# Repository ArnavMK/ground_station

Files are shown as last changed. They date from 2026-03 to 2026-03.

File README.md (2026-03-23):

# Glacadóir: Handheld Rocketry Ground Station

**3D Render:**

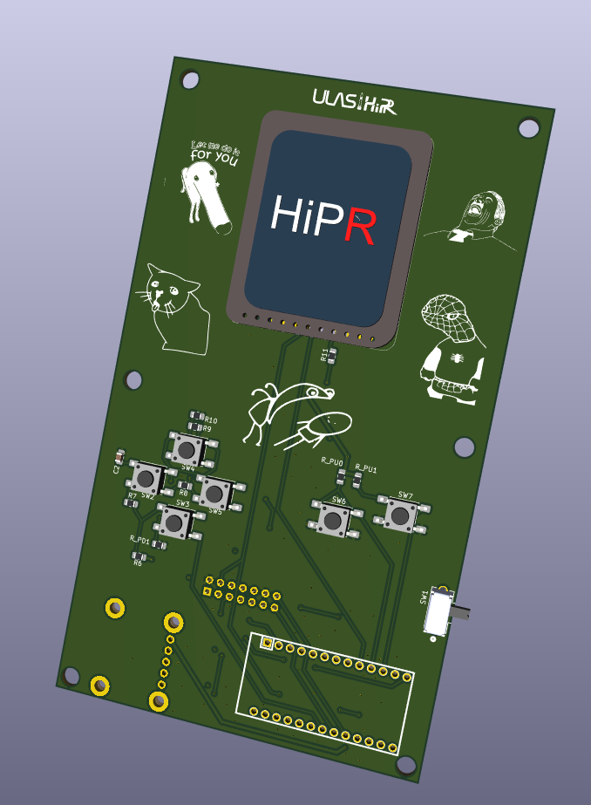
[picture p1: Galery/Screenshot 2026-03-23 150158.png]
Screenshot 2026-03-23 150607.png


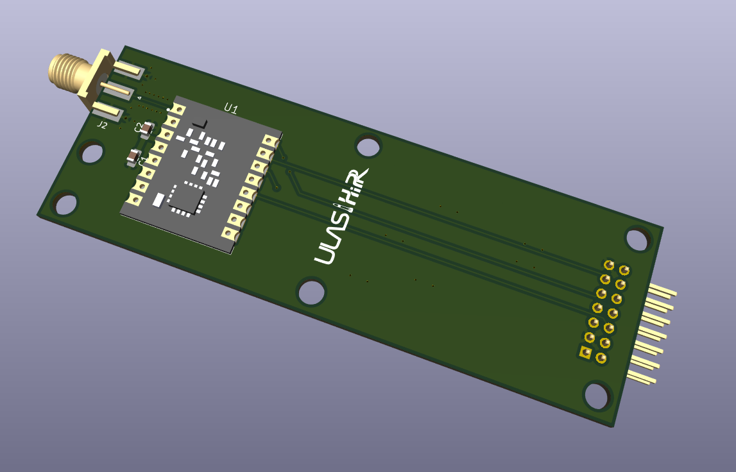
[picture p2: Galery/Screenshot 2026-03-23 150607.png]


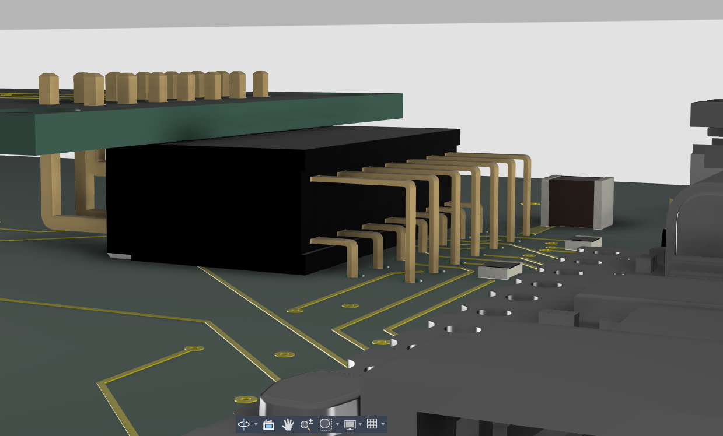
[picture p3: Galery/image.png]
Screenshot 2026-03-23 150158.png


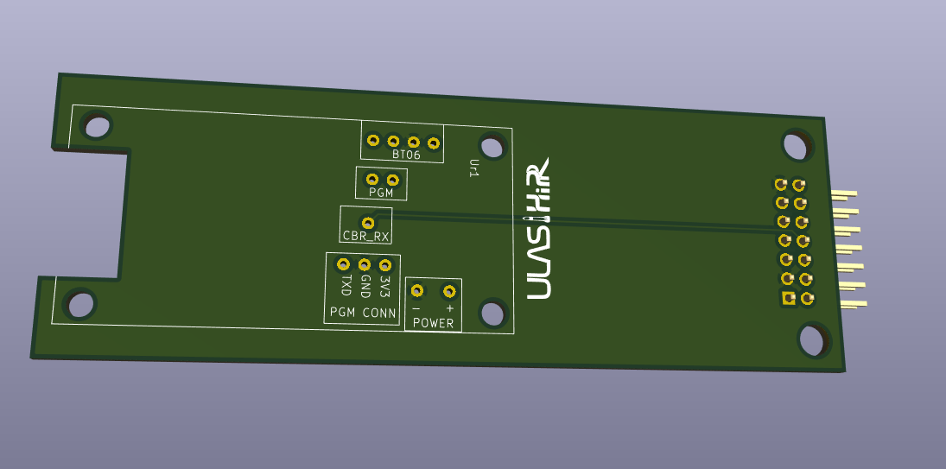
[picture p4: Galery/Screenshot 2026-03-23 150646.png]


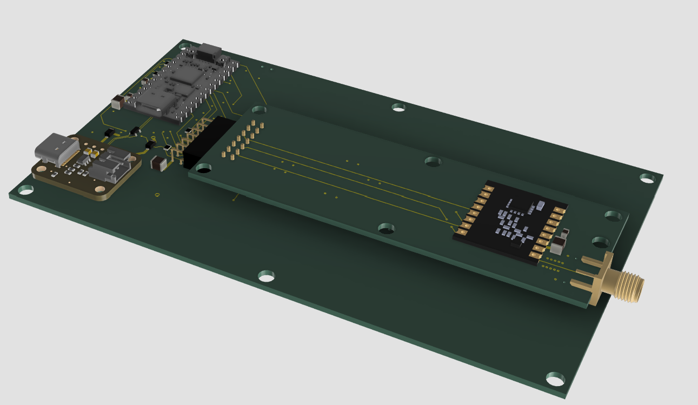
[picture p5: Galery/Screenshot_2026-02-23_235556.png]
Screenshot 2026-03-23 150227.png


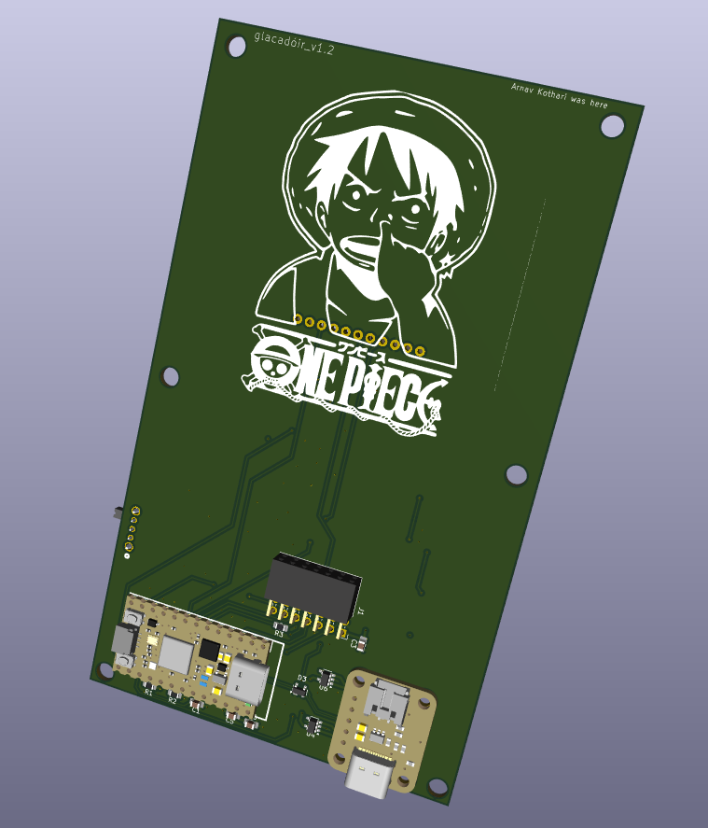
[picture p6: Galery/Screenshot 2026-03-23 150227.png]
Screenshot 2026-03-23 150646.png


**PCB Layout (Rev 1.2):**

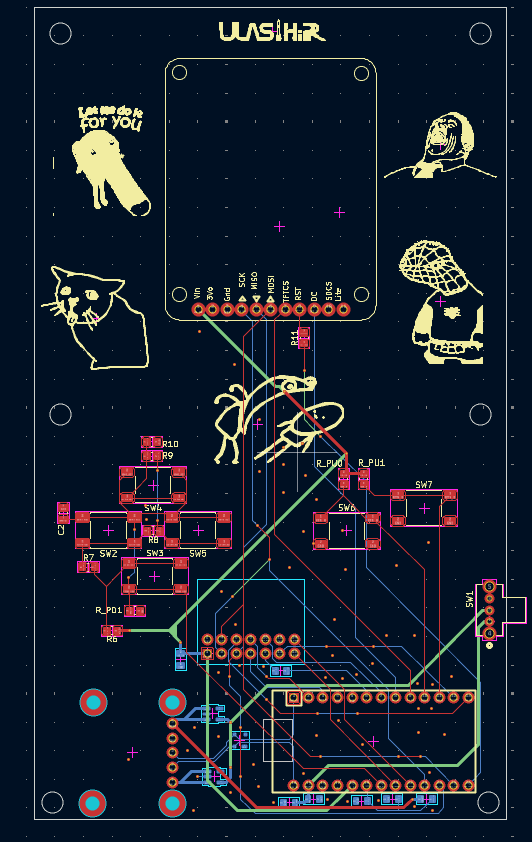
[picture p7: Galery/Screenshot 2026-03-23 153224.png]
Screenshot 2026-03-23 153224.png


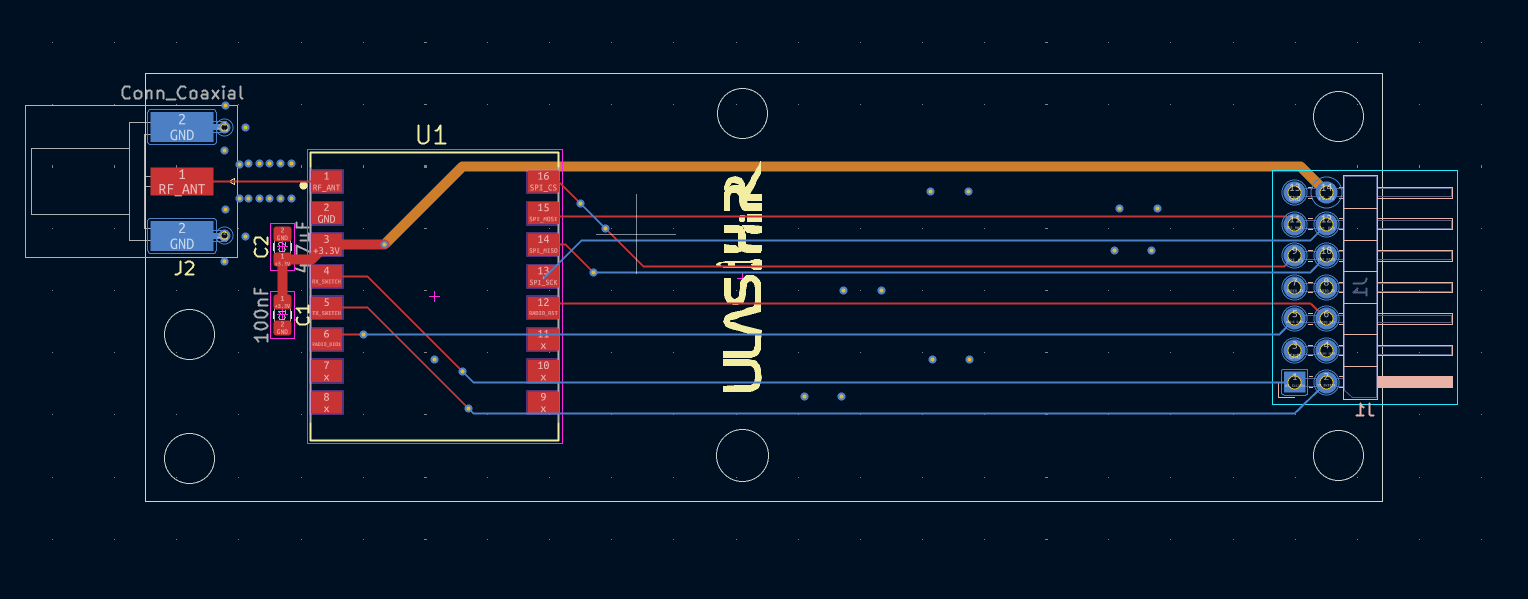
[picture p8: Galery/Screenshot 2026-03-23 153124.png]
Screenshot 2026-03-23 153124.png


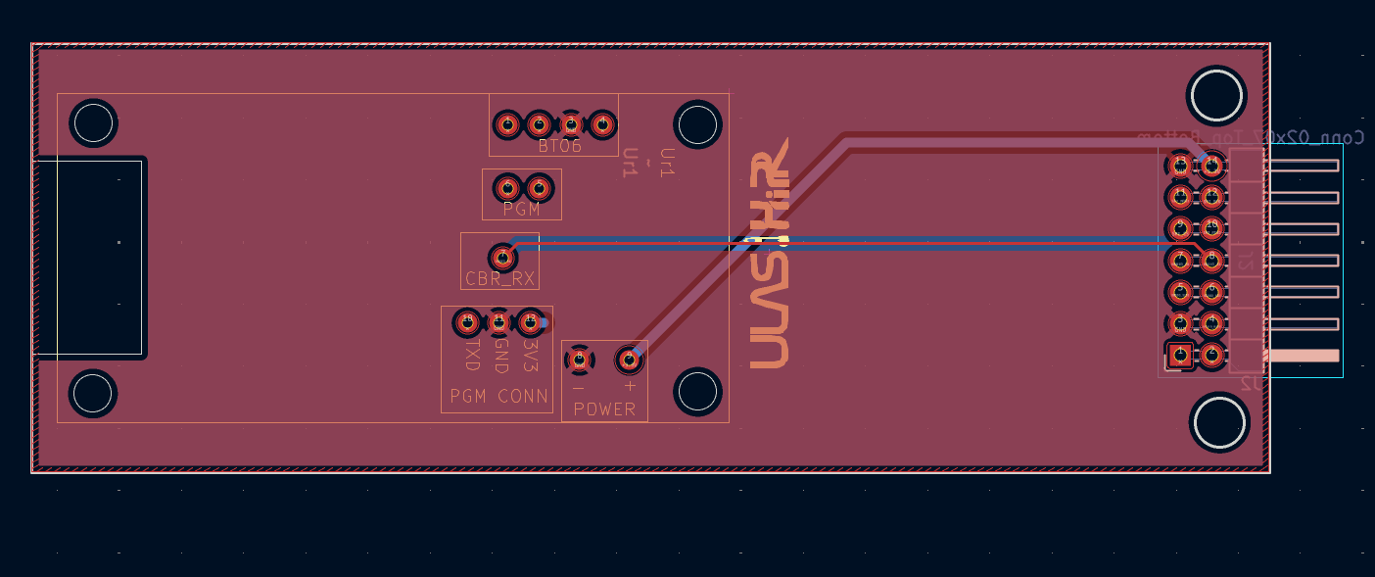
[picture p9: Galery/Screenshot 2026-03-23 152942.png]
Screenshot 2026-03-23 152942.png


### What is this project?

Glacadóir is a custom handheld telemetry terminal designed to receive, process, and visualize real-time data from high-power rockets. It serves as the primary interface for the **ULAS HiPR** team during the **Mach 2026** and **Euroc 2026** competition.

This board acts as a portable "command center," featuring:

- **Adafruit KB2040 (RP2040):** The brain handling high-speed data processing.
- **Radio expansion cartridges:** A game boy style cartridge system that enables the ground station to adapt to different radio protocols like UART (Eggfinder RX) and SPI (LoRa)
- **IPS Display:** Real-time visualization of flight curves and GPS coordinates.
- **Power Management:** A dual-input "Ideal Diode" with Micro Lipo battery charger system for seamless USB/Battery switching. (also data transfer).

### How to use it?

Glacadóir is designed for field portability. It connects to a standard 868MHz SMA antenna and is powered by a single-cell LiPo battery.

1. **Telemetry:** Receives flight data via the radio protocol attached and displays it on the internal IPS screen.
2. **Interaction:** A 5-button navigational matrix allows the user to switch between data screens (velocity, altitude, GPS).
3. **Expansion:** Features a dedicated UART/SPI expansion port to connect external modules like an Eggtimer or secondary radio adapters.
4. **Charging:** Integrated USB-C charging allows for field-topping while the station remains active.

### 3D enclosure cad
there is no proper enclosure cad yet, but it will be inspired by a gameboy and cartridge design like so
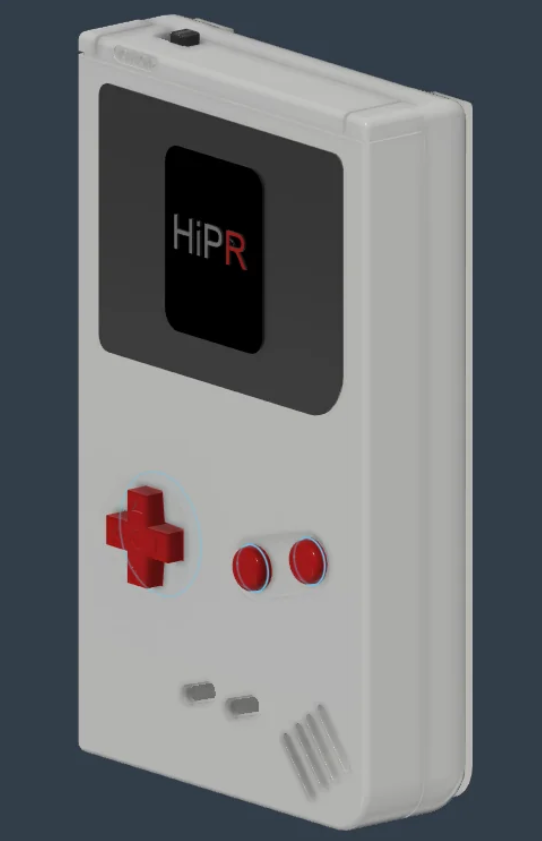
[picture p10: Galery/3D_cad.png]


### Why I made it

This project was made for the ULAS HiPR’s ground station needs. 

---

### Bill of Materials (BOM) - Rev 1.2

| Part | Amount | Link | Cost |
| --- | --- | --- | --- |
| MicroLipo charger | 1 | [Link](https://www.digikey.ie/en/products/detail/adafruit-industries-llc/1904/5054545) | 6.95 |
| Display | 1 | [Link](https://www.digikey.ie/en/products/detail/adafruit-industries-llc/5206/15204095) | 17.5 |
| Main Power Switch | 1 | [Link](https://www.digikey.com/en/products/detail/c-k/OS102011MA1QN1/1981430) | 0.65 |
|  |  |  |  |
| Tactile Switches | 6 | [Link](https://www.digikey.com/en/products/detail/e-switch/TL3301AF160QG/378993) | 0.39 |
| SP0503BAHT ESD diode array | 1 | [Link](https://www.digikey.com/en/products/detail/littelfuse-inc/SP0503BAHTG/1154308) | 0.53 |
| 0805 resistor package (10k) | 11 | [Link](https://www.digikey.com/en/products/detail/bourns-inc/CR0805-FX-1002ELF/3593209) | 0.1 |
| 0805 resistor package (100K) | 2 | [Link](https://www.digikey.com/en/products/detail/bourns-inc/CR0805-FX-1003ELF/3740947) | 0.1 |
| 0805 resistor package (200K) | 1 | [Link](https://www.digikey.com/en/products/detail/bourns-inc/CR0805-FX-2003ELF/3784733) | 0.1 |
| 0805 capacitor package (0.1uF) | 4 | [Link](https://www.digikey.com/en/products/detail/nextgen-components/0805B104K500BD/15776052) | 0.078 |
| 0805 capacitor package (10uF) | 1 | [Link](https://www.digikey.com/en/products/detail/nextgen-components/0805W106K250CC/18676983) | 0.17 |
| 0805 capacitor package (4.7uF) | 2 | [Link](https://www.digikey.com/en/products/detail/nextgen-components/0805B475K160CC/22601960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) | 0.34 |
| Analog divices Ideal Diodes MAX40200 | 2 | [Link](https://www.digikey.ie/en/products/detail/analog-devices-inc-maxim-integrated/MAX40200AUK-T/7599791) | 1.89 |
| Female SMA connector | 1 | [Link](https://www.digikey.ie/en/products/detail/molex/0732511153/11305709) | 3.9 |
| Lora Module | 1 | [Link](https://www.digikey.com/en/products/detail/rf-solutions/RF-LORA-868-SO/5291460) | 20.16 |
| Eggfinder (already have it) | 1 | — | — |
| Radio adapter Female connector. (already have it) | 1 | — | — |
| KB2040 MCU | 1 | [Link](https://www.adafruit.com/product/5302) | 8.95 |
|  |  |  |  |
| **Total SUM** |  |  | **61.808** |

**Total Estimated Component Cost: ~€62.00** (Excluding shipping/PCBs)

### Key Technical Revisions (Rev 1.2)

- **Ideal Diode Logic:** Swapped standard Schottky diodes for MAX40200 "Ideal" diodes to reclaim $500\text{mV}$ of battery headroom, ensuring stability deep into the discharge cycle.
- **RF Signal Integrity:** Implemented a $50\,\Omega$ coplanar waveguide ($0.1565\text{ mm}$ trace, $0.508\text{ mm}$ clearance) with via-fencing to maximize 868MHz range.
- **Expansion Logic:** Corrected the UART crossover (CBR_RX to RADIO_TX) to allow bi-directional communication with Eggtimer adapters.
- **Signal Cleanup:** Removed pull-up resistors on actively driven SPI lines (SCK/MOSI) to maintain sharp digital transitions at high clock speeds.

---

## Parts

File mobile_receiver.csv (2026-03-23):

Reference | Qty | Value | DNP | Exclude from BOM | Exclude from Board | Footprint | Datasheet
C1,C2,C5 | 3 | 0.1µF |  |  |  | Capacitor_SMD:C_0805_2012Metric_Pad1.18x1.45mm_HandSolder | ~
C3 | 1 | 10uF |  |  |  | Capacitor_SMD:C_0805_2012Metric_Pad1.18x1.45mm_HandSolder | ~
C6 | 1 | 4.7µF |  |  |  | Capacitor_SMD:C_0805_2012Metric_Pad1.18x1.45mm_HandSolder | ~
D3 | 1 | SP0503BAHT |  |  |  | Package_TO_SOT_SMD:SOT-143 | http://www.littelfuse.com/~/media/files/littelfuse/technical%20resources/documents/data%20sheets/sp05xxba.pdf
J1 | 1 | Conn_02x07_Top_Bottom |  |  |  | Connector_PinSocket_2.54mm:PinSocket_2x07_P2.54mm_Horizontal | ~
R1 | 1 | 200K |  |  |  | Resistor_SMD:R_0805_2012Metric_Pad1.20x1.40mm_HandSolder | ~
R2,R_PD1 | 2 | 100K |  |  |  | Resistor_SMD:R_0805_2012Metric_Pad1.20x1.40mm_HandSolder | ~
R3,R6,R7,R8,R9,R10,R_PU0,R_PU1 | 8 | 10K |  |  |  | Resistor_SMD:R_0805_2012Metric_Pad1.20x1.40mm_HandSolder | ~
R11 | 1 | 10KΩ |  |  |  | Resistor_SMD:R_0805_2012Metric_Pad1.20x1.40mm_HandSolder | ~
SW1 | 1 | SW_SPST |  |  |  | My footprints:OS102011MA1QN1_CNK | ~
SW2,SW3,SW4,SW5,SW6,SW7 | 6 | SW_Push |  |  |  | Button_Switch_SMD:SW_Push_1P1T_NO_E-Switch_TL3301NxxxxxG | ~
U1 | 1 | ~ |  |  |  | My footprints:4410_Micro_LiPo_USBC
U2 | 1 | kb2040 |  |  |  | My footprints:kb2040
U3 | 1 | ~ |  |  |  | My footprints:Adafruit_280X240_Display
U4,U6 | 2 | MAX40200AUK |  |  |  | Package_TO_SOT_SMD:SOT-23-5 | https://datasheets.maximintegrated.com/en/ds/MAX40200.pdf

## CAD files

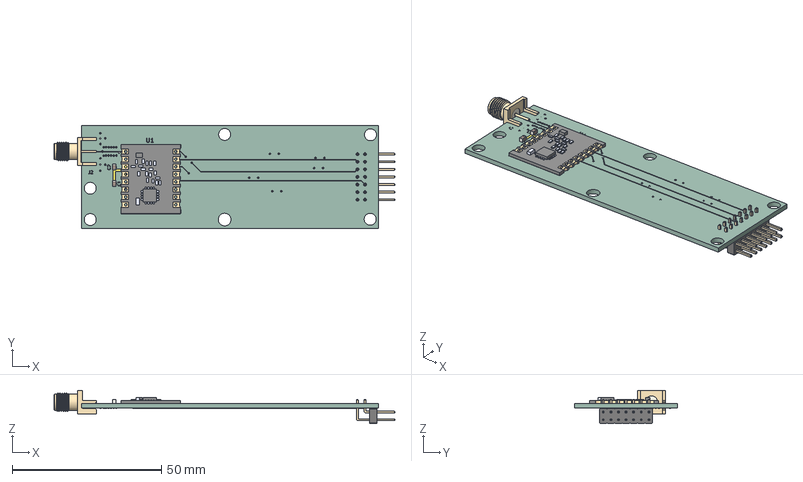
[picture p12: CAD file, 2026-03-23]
Hardware/SPI_adapter/SPI_adapter.step
114.2 x 34.5 x 11.1 mm
C_0805_2012Metric x 2
RF-LORA-868-SO
SMA_Molex_73251-1153_EdgeMount_Horizontal
PinHeader_2x07_P2.54mm_Horizontal
SPI_adapter_copper
SPI_adapter_via
SPI_adapter_silkscreen x 2
SPI_adapter_PCB

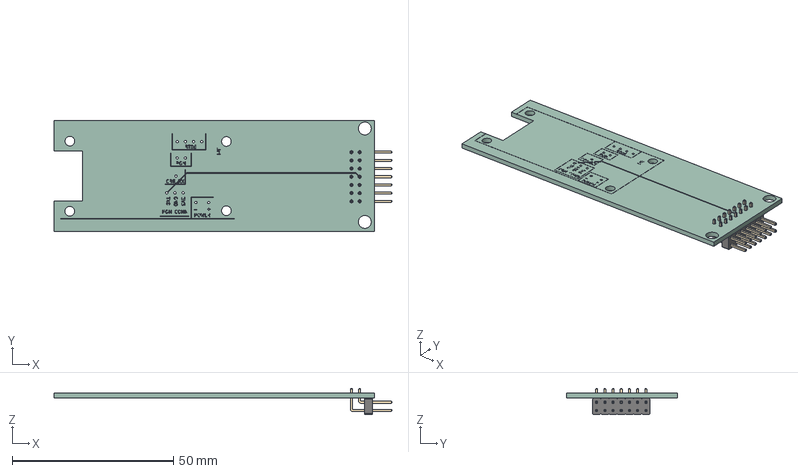
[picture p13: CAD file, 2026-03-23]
Hardware/UART_adapter/UART_adapter.step
104.9 x 34.5 x 8.08 mm
PinHeader_2x07_P2.54mm_Horizontal
UART_adapter_copper
UART_adapter_silkscreen x 2
UART_adapter_PCB

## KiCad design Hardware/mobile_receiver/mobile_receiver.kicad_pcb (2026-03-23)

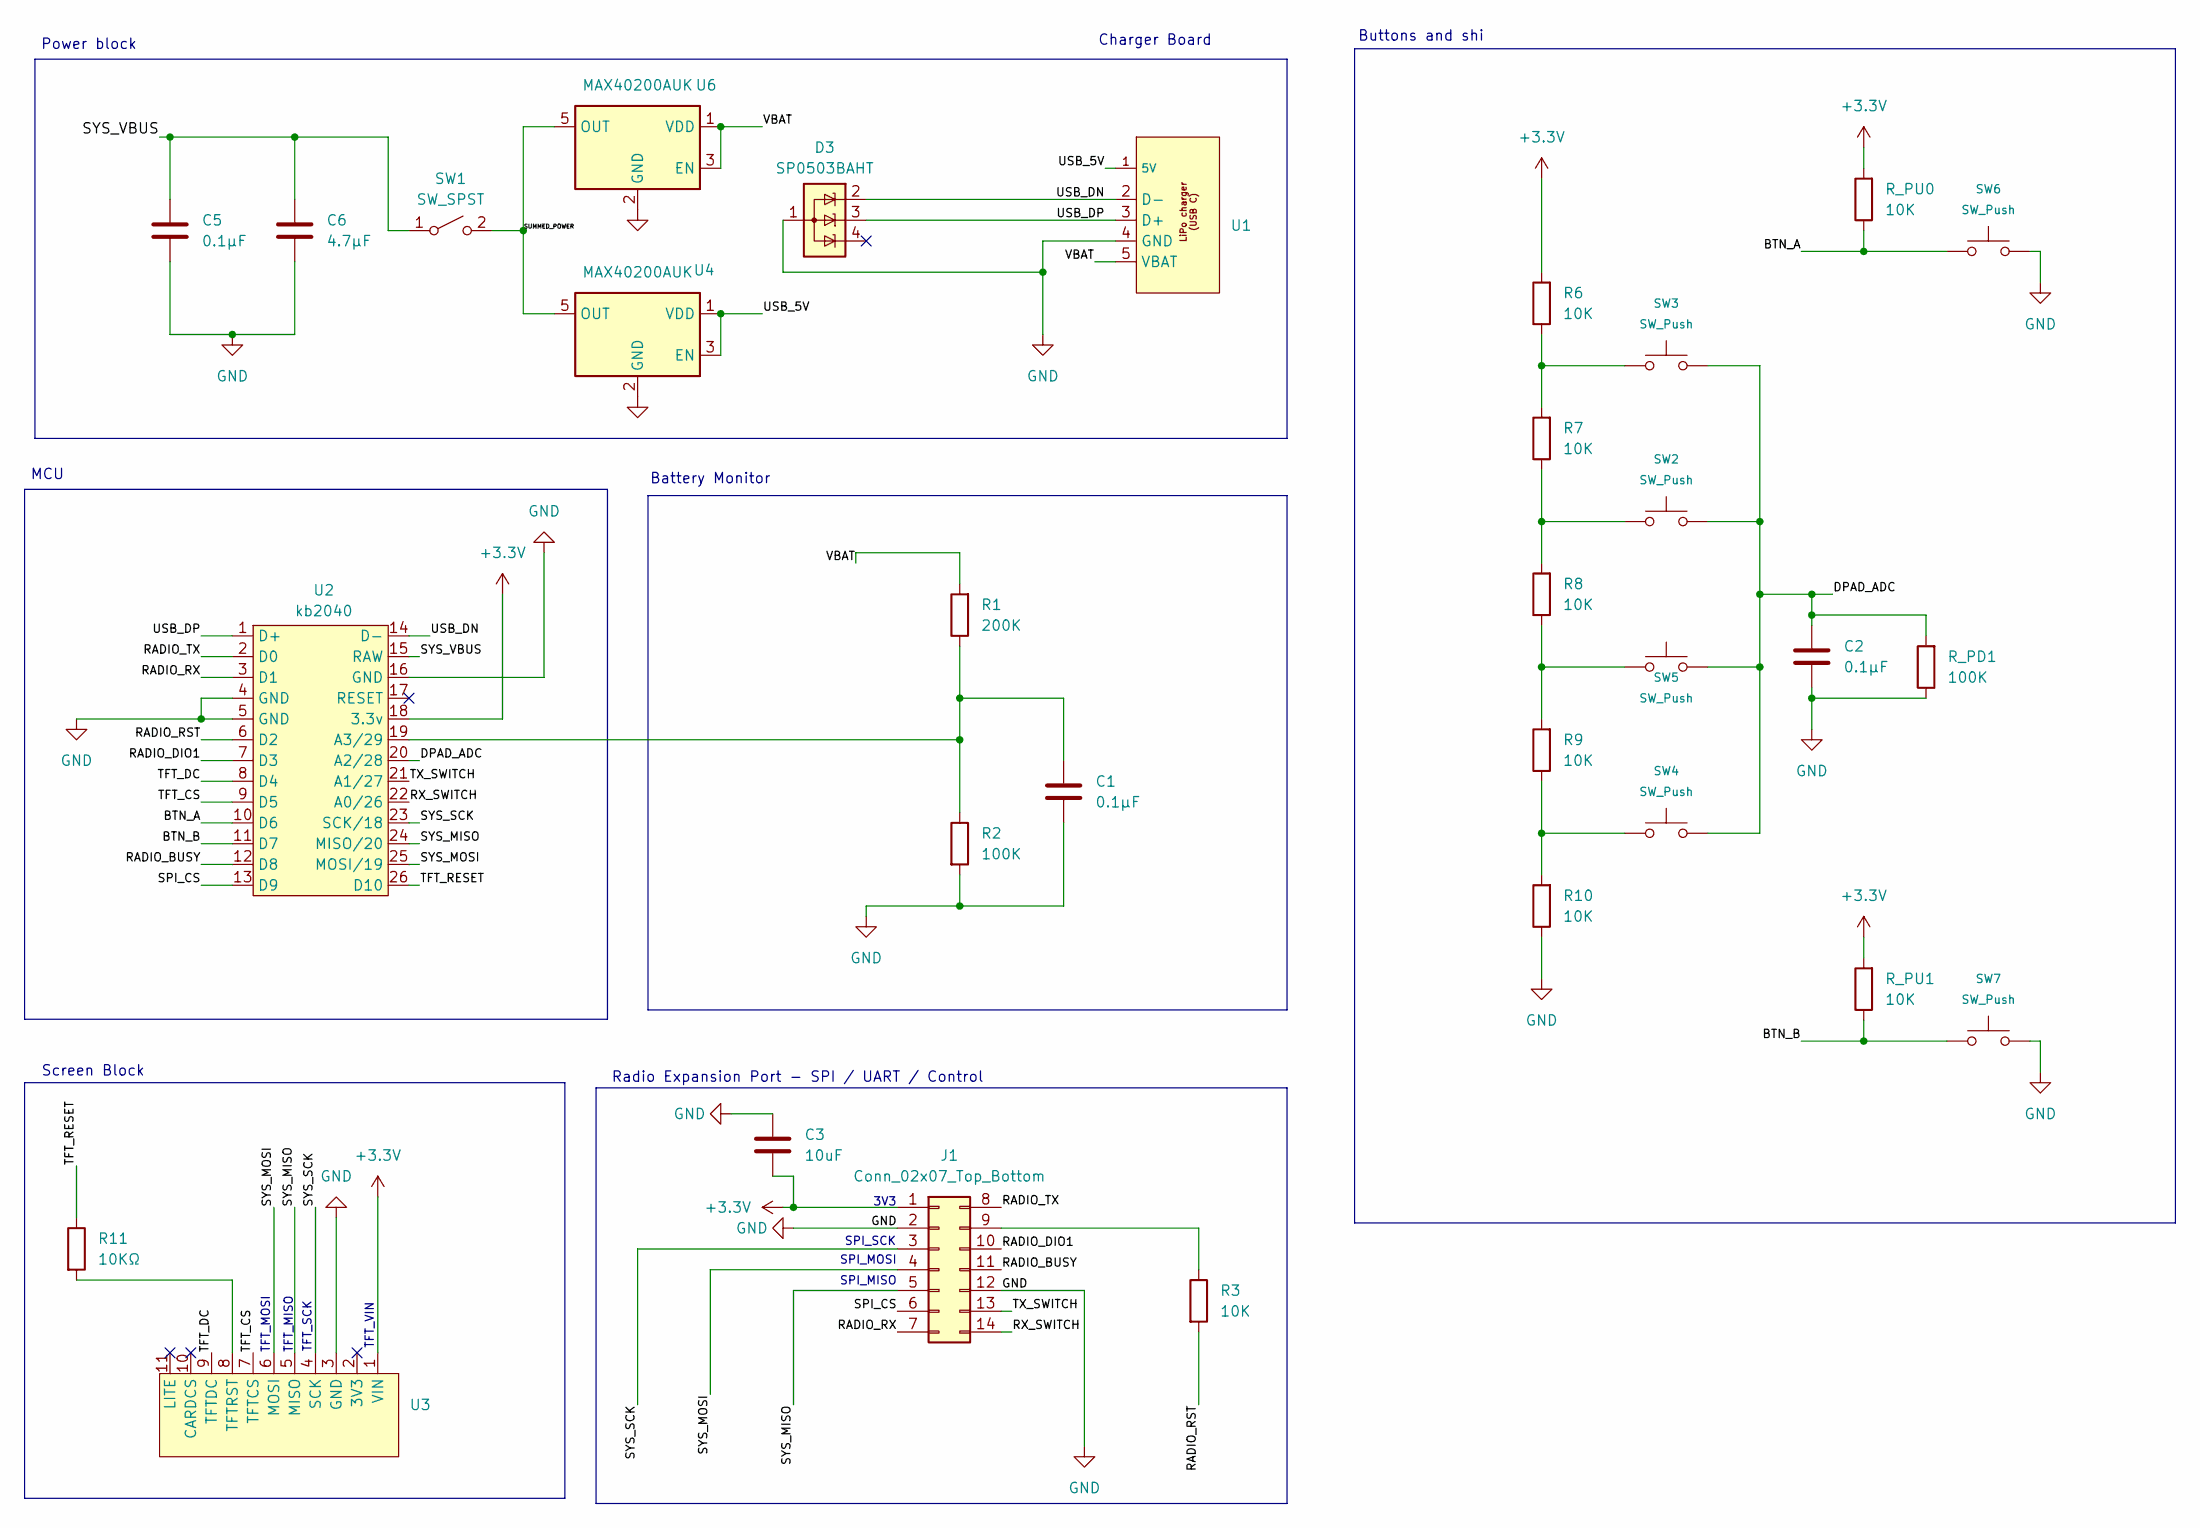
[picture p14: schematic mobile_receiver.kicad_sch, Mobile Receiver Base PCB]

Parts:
C1, C2, C5: 0.1µF; C_0805_2012Metric_Pad1.18x1.45mm_HandSolder
C3: 10uF; C_0805_2012Metric_Pad1.18x1.45mm_HandSolder
C6: 4.7µF; C_0805_2012Metric_Pad1.18x1.45mm_HandSolder
D3: SP0503BAHT; SOT-143
J1: Conn_02x07_Top_Bottom; PinSocket_2x07_P2.54mm_Horizontal
R1: 200K; R_0805_2012Metric_Pad1.20x1.40mm_HandSolder
R2: 100K; R_0805_2012Metric_Pad1.20x1.40mm_HandSolder
R3, R6, R7, R8, R9, R10: 10K; R_0805_2012Metric_Pad1.20x1.40mm_HandSolder
R11: 10KΩ; R_0805_2012Metric_Pad1.20x1.40mm_HandSolder
R_PD1: 100K; R_0805_2012Metric_Pad1.20x1.40mm_HandSolder
R_PU0, R_PU1: 10K; R_0805_2012Metric_Pad1.20x1.40mm_HandSolder
SW1: SW_SPST; OS102011MA1QN1_CNK
SW2, SW3, SW4, SW5, SW6, SW7: SW_Push; SW_Push_1P1T_NO_E-Switch_TL3301NxxxxxG
U1: 4410_Micro_LiPo_USBC
U2: kb2040
U3: Adafruit_280X240_Display
U4, U6: MAX40200AUK; SOT-23-5

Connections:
+3.3V: C3.2, J1.1, R6.2, R_PU0.2, R_PU1.2, U2.18 (3.3v), U3.1 (VIN)
/BTN_A: R_PU0.1, SW6.1, U2.10 (D6)
/BTN_B: R_PU1.1, SW7.1, U2.11 (D7)
/DPAD_ADC: C2.1, R_PD1.2, SW2.2, SW3.2, SW4.2, SW5.2, U2.20 (A2/28)
/RADIO_BUSY: J1.11, U2.12 (D8)
/RADIO_DIO1: J1.10, U2.7 (D3)
/RADIO_RST: R3.2, U2.6 (D2)
/RADIO_RX: J1.7, U2.3 (D1)
/RADIO_TX: J1.8, U2.2 (D0)
/RX_SWITCH: J1.14, U2.22 (A0/26)
/SPI_CS: J1.6, U2.13 (D9)
/SUMMED_POWER: SW1.2 (B), U4.5 (OUT), U6.5 (OUT)
/SYS_MISO: J1.5, U2.24 (MISO/20), U3.5 (MISO)
/SYS_MOSI: J1.4, U2.25 (MOSI/19), U3.6 (MOSI)
/SYS_SCK: J1.3, U2.23 (SCK/18), U3.4 (SCK)
/SYS_VBUS: C5.1, C6.1, SW1.1 (A), U2.15 (RAW)
/TFT_CS: U2.9 (D5), U3.7 (TFTCS)
/TFT_DC: U2.8 (D4), U3.9 (TFTDC)
/TFT_RESET: R11.1, U2.26 (D10)
/TX_SWITCH: J1.13, U2.21 (A1/27)
/USB_5V: U1.1 (5V), U4.1 (VDD), U4.3 (EN)
/USB_DN: D3.2 (K), U1.2 (D-), U2.14 (D-)
/USB_DP: D3.3 (K), U1.3 (D+), U2.1 (D+)
/VBAT: R1.2, U1.5 (VBAT), U6.1 (VDD), U6.3 (EN)
GND: C1.2, C2.2, C3.1, C5.2, C6.2, D3.1 (A), J1.2, J1.12, R2.2, R10.1, R_PD1.1, SW6.2, SW7.2, U1.4 (GND), U2.4 (GND), U2.5 (GND), U2.16 (GND), U3.3 (GND), U4.2 (GND), U6.2 (GND)
unnamed: J1.9, R3.1
unnamed: R6.1, R7.2, SW3.1
unnamed: R7.1, R8.2, SW2.1
unnamed: R8.1, R9.2, SW5.1
unnamed: R9.1, R10.2, SW4.1
unnamed: C1.1, R1.1, R2.1, U2.19 (A3/29)
unnamed: R11.2, U3.8 (TFTRST)

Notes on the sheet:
TFT_MOSI
Radio Expansion Port - SPI / UART / Control
3V3
Screen Block
TFT_SCK
MCU
Buttons and shi
TFT_MISO
TFT_VIN
Battery Monitor
SPI_MOSI
SPI_SCK
Charger Board
SPI_MISO
Power block

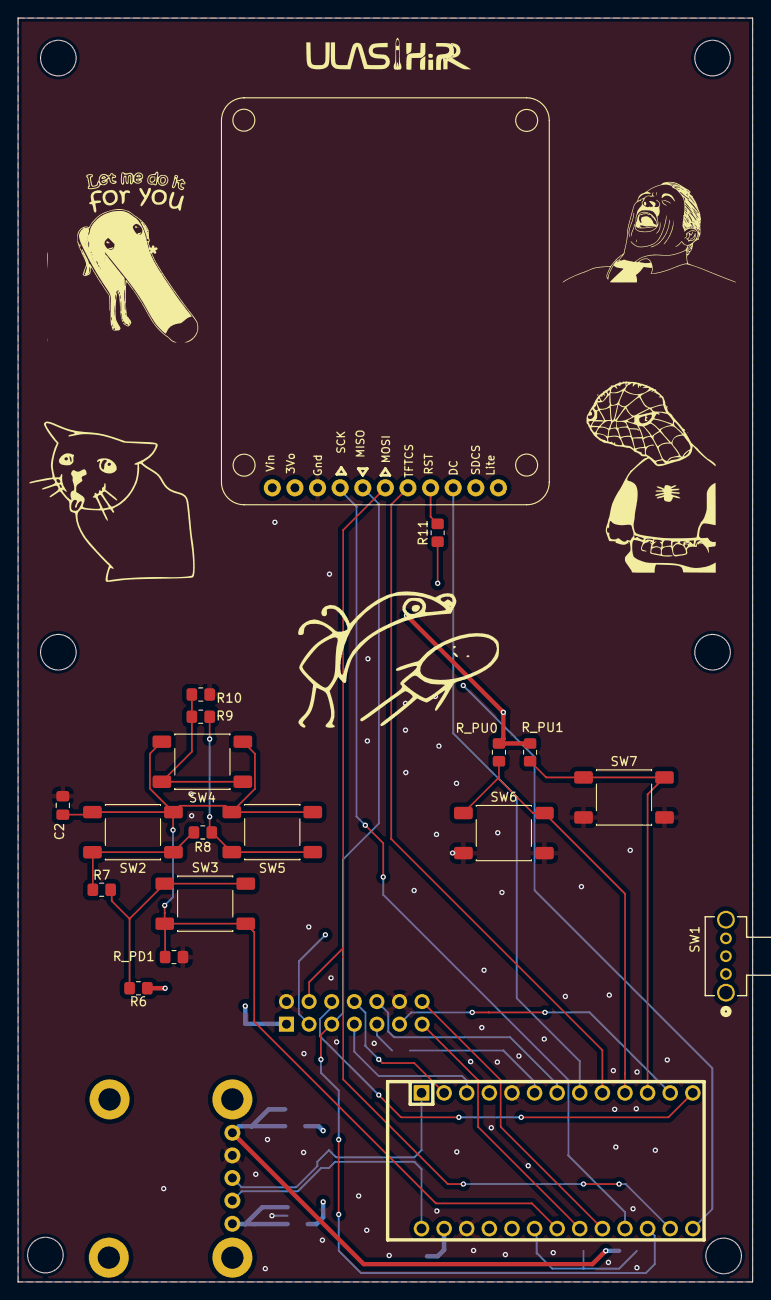
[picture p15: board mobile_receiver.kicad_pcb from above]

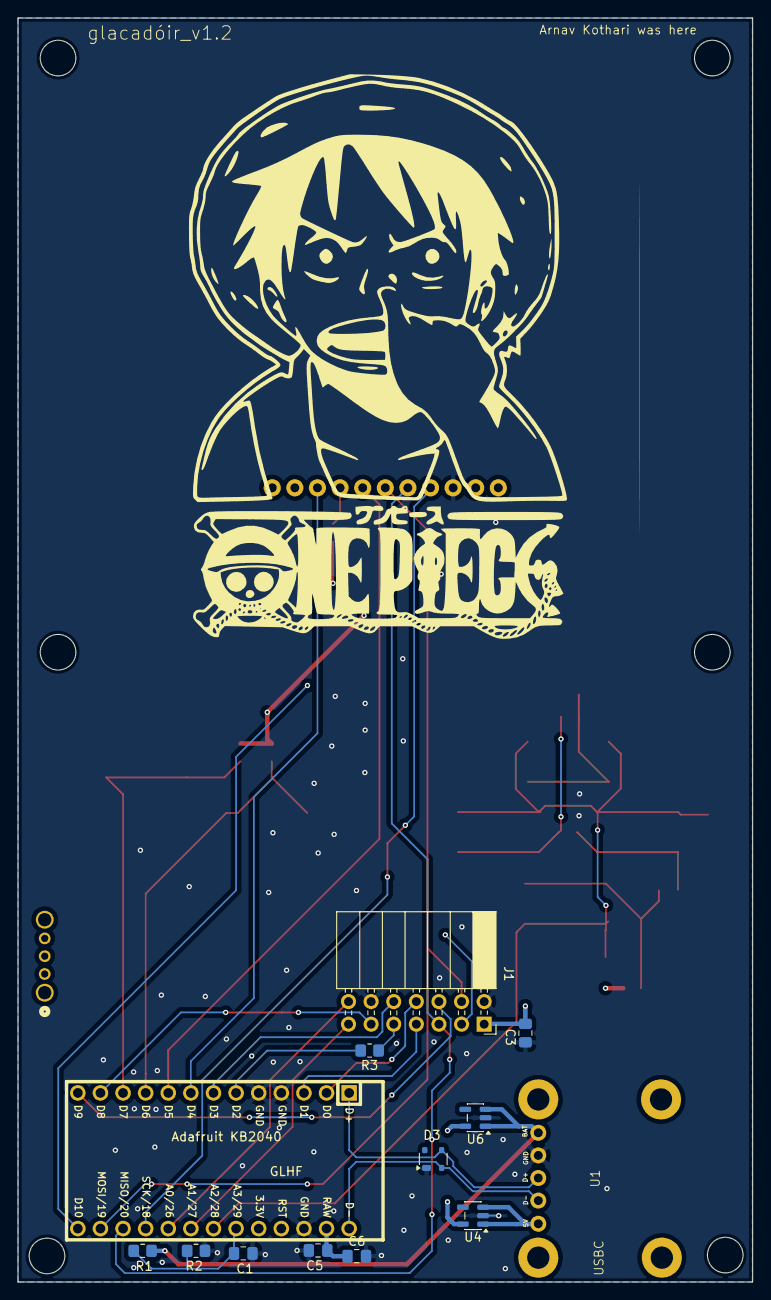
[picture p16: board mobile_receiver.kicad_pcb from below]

Board: 4 copper layers, 82.5 x 142.0 mm, 31 parts (13 on the bottom side), 32 nets.

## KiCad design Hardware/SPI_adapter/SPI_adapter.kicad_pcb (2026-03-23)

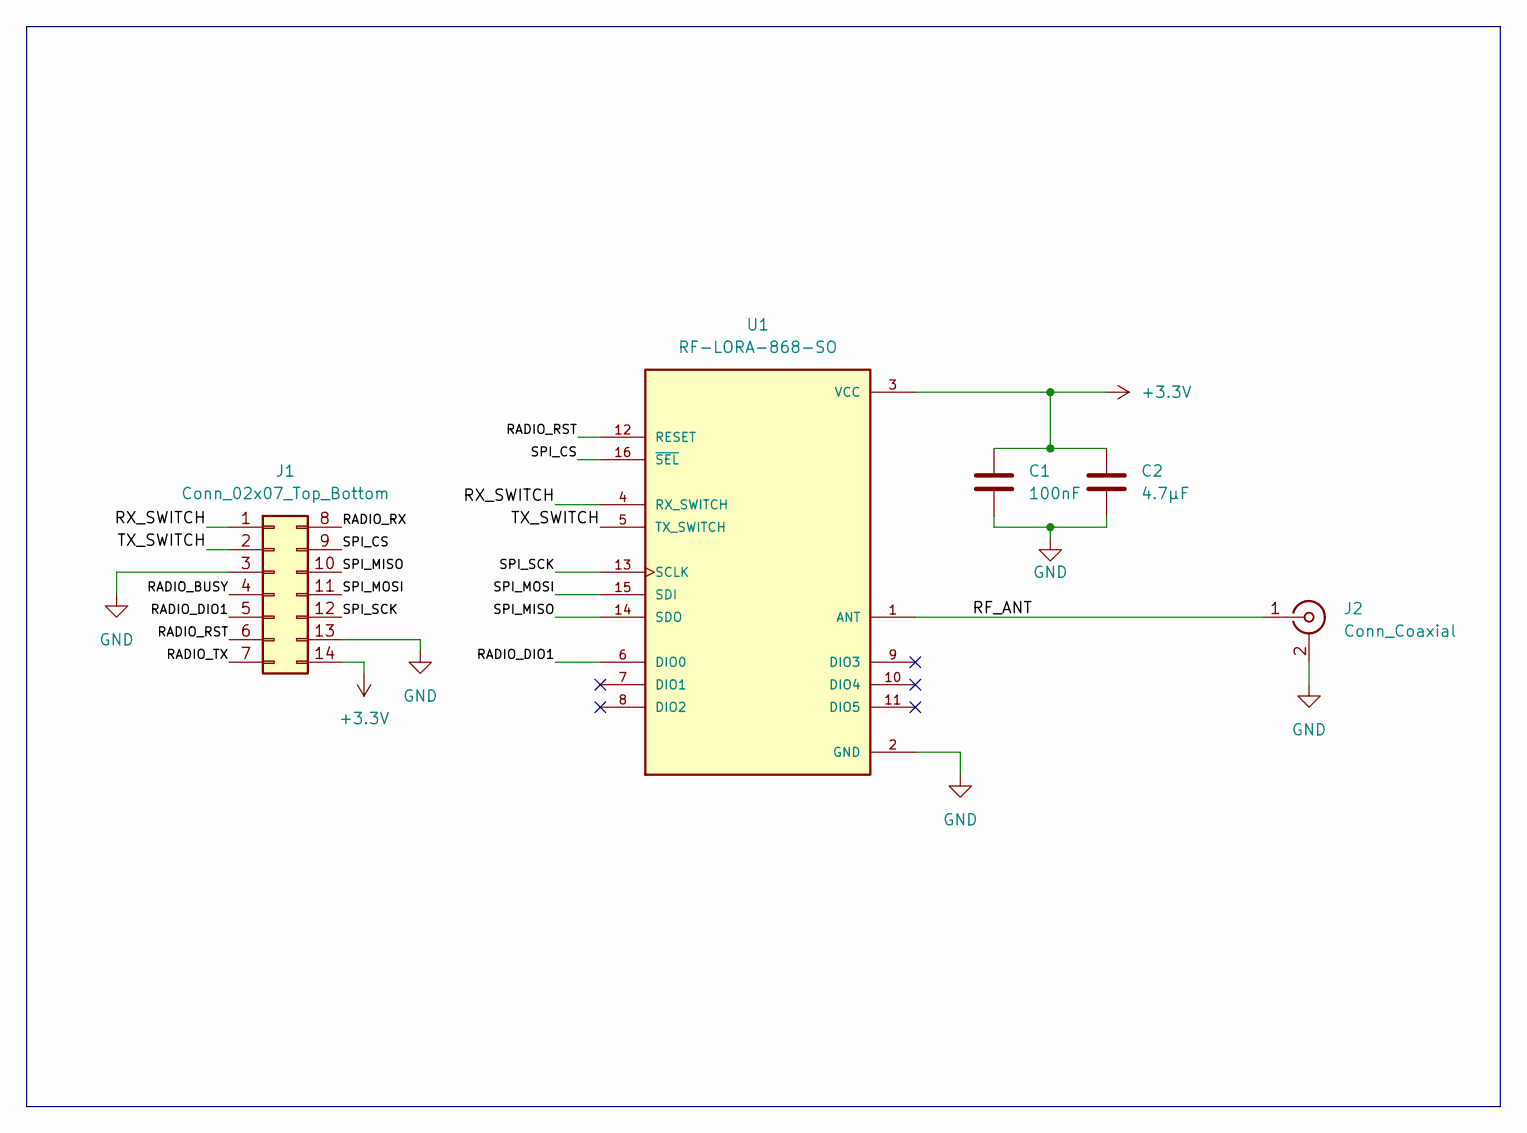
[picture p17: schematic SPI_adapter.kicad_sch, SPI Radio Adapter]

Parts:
C1: 100nF; C_0805_2012Metric_Pad1.18x1.45mm_HandSolder
C2: 4.7µF; C_0805_2012Metric_Pad1.18x1.45mm_HandSolder
J1: Conn_02x07_Top_Bottom; PinHeader_2x07_P2.54mm_Horizontal
J2: Conn_Coaxial; SMA_Molex_73251-1153_EdgeMount_Horizontal
U1: RF-LORA-868-SO; XCVR_RF-LORA-868-SO

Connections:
+3.3V: C1.1, C2.1, J1.14, U1.3 (VCC)
/RADIO_BUSY: J1.4
/RADIO_DIO1: J1.5, U1.6 (DIO0)
/RADIO_RST: J1.6, U1.12 (RESET)
/RADIO_RX: J1.8
/RADIO_TX: J1.7
/RF_ANT: J2.1 (In), U1.1 (ANT)
/RX_SWITCH: J1.1, U1.4 (RX_SWITCH)
/SPI_CS: J1.9, U1.16 (~SEL)
/SPI_MISO: J1.10, U1.14 (SDO)
/SPI_MOSI: J1.11, U1.15 (SDI)
/SPI_SCK: J1.12, U1.13 (SCLK)
/TX_SWITCH: J1.2, U1.5 (TX_SWITCH)
GND: C1.2, C2.2, J1.3, J1.13, J2.2 (Ext), U1.2 (GND)

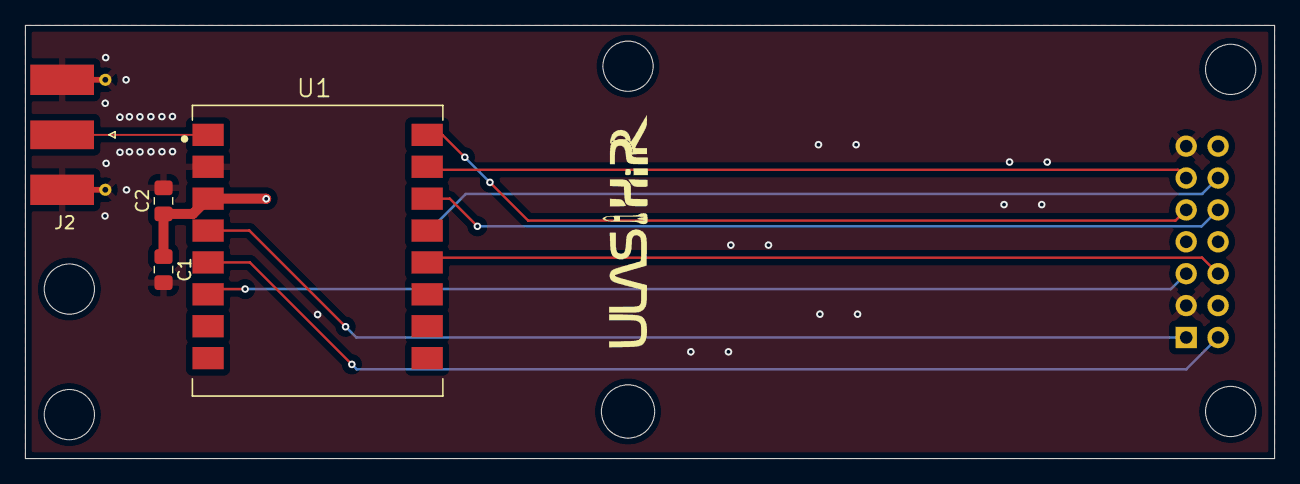
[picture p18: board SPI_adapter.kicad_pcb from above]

Board: 4 copper layers, 99.5 x 34.5 mm, 5 parts (1 on the bottom side), 11 nets.

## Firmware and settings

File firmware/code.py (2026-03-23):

import board
import displayio
import terminalio
from adafruit_display_text import label
from fourwire import FourWire
import time
import busio
import digitalio

from adafruit_st7789 import ST7789
from gps_data import GPS_Data
from screens import GPS_Screen, Radio_Screen



displayio.release_displays()


spi = busio.SPI(board.SCK, board.MOSI, board.MISO)
tft_cs = board.D5
tft_dc = board.D3
tft_rst = board.D4

small_bus = FourWire(spi, command=tft_dc, chip_select=tft_cs, reset=tft_rst)

gps_screen = GPS_Screen(small_bus)


last_data = time.time()
last_gps_data = GPS_Data()
last_gps_time = time.time()
rssi = None
gps_screen.update(last_gps_data)


while True:
    packet = "fake data"

    if packet is None:
        rssi = None
    else:
        last_data = time.time()

        data = str(packet, "utf-8")
        gps_data = GPS_Data(data.split(","))
        
        gps_screen.update(gps_data)

        last_gps_time = gps_data.fix_time

    time.sleep(0.5)

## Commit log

2026-03-23 Project commit
    [SPI_adapter-B_Cu.gbl, SPI_adapter-B_Mask.gbs, SPI_adapter-B_Paste.gbp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]
2026-03-23 read me rev 1
    *you will find the bom.csv in the root directory* added to the README.
2026-03-23 Update README with additional project screenshots
    Added multiple screenshots to the README for better visualization of the project, including 3D renders and PCB layouts.
2026-03-23 Add 3D enclosure CAD section to README
    Added section about 3D enclosure CAD inspired by Gameboy design.
2026-03-23 Fix image link format for 3D CAD enclosure
    Updated image syntax for 3D enclosure CAD in README.
